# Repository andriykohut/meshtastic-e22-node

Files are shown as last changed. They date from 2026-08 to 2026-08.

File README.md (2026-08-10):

# 433 MHz Meshtastic node

A Meshtastic node built around an ESP32-S3 dev board and an Ebyte E22-400M22S, running on a
2P 18650 pack. Mostly assembled from parts I already had. I wrote this up so I can rebuild it
in a year when I've forgotten how it goes together.

Not a product, not a kit. A dev board, a LoRa module and a GPS on perfboard in a printed box.

## Hardware

| | |
|---|---|
| MCU | ESP32-S3-DevKitC-1 |
| Radio | Ebyte E22-400M22S — SX1268 + PA/LNA, 410–493 MHz |
| GPS | GY-NEO8MV2 (u-blox NEO-8M) |
| Display | SSD1306 128×64, I²C |
| Power | 2× 18650 parallel, TP4056 charger, TPS63020 buck-boost to 3.3 V |
| Region | EU_433 |

## Layout

```
firmware/     variant.h and the platformio env to build it
hardware/     wiring diagrams, netlist, KiCad schematic
docs/         build notes, BOM, troubleshooting
```

## Building the firmware

No stock Meshtastic target fits this hardware, so it needs compiling from source. The E22 has
an external PA whose LNA side needs an RXEN pin driven by the MCU, and nothing prebuilt drives
an arbitrary GPIO for that.

```bash
make upload    # clones meshtastic/firmware into build/firmware, installs variant.h + the
               # platformio env, then flashes
make monitor
```

Then set the region, or it won't transmit at all:

```bash
make configure   # meshtastic --set lora.region EU_433 / lora.modem_preset LONG_FAST
```

See `Makefile` for the full set of targets (`build`, `upload`, `monitor`, `ports`, `configure`,
`validate`, plus `setup`/`harness`/`kicad` for the Python hardware tooling below).

## Wiring

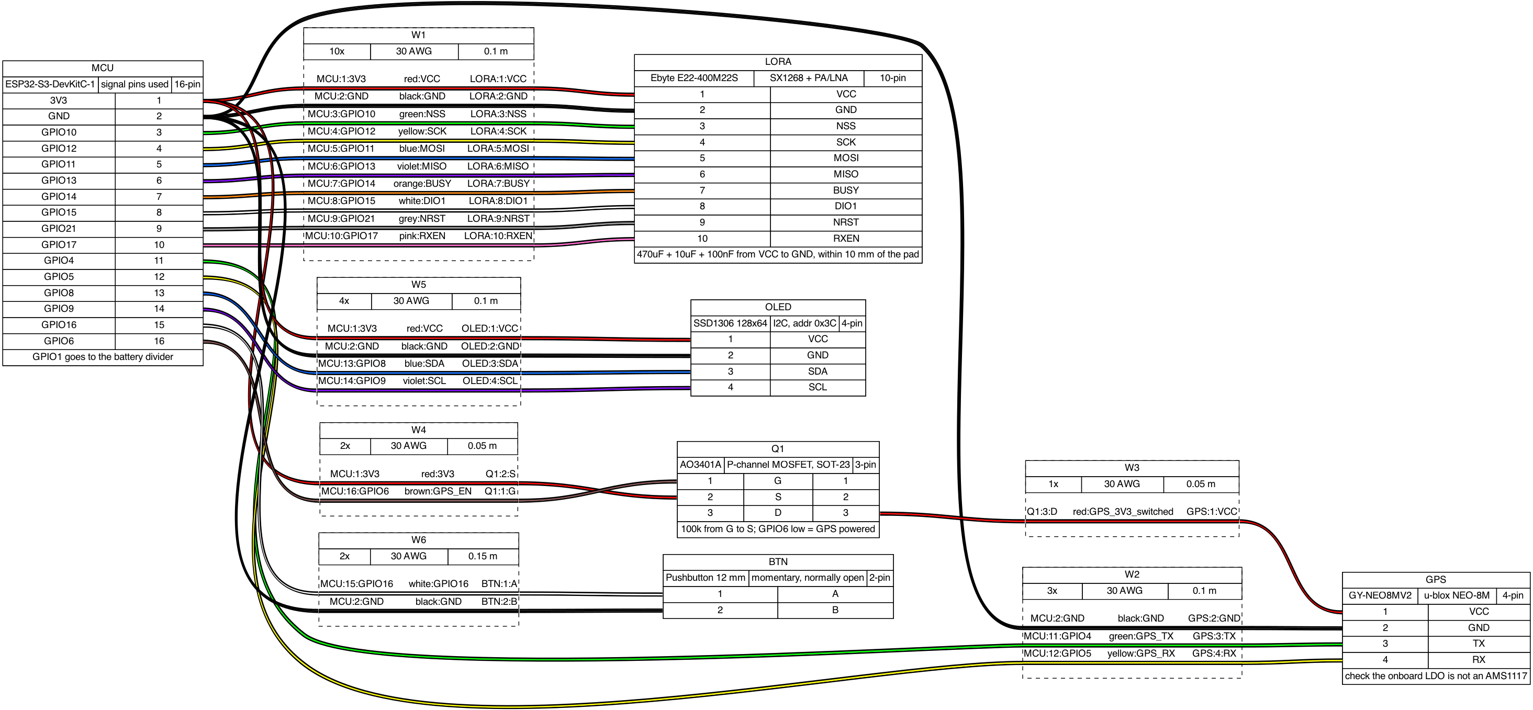
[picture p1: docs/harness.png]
harness


Signal harness above, power section in [docs/power-schematic.svg](docs/power-schematic.svg).
The harness diagram is generated from `hardware/harness.yml` with
[WireViz](https://github.com/wireviz/WireViz) — edit the YAML, run `make harness` (uses
[uv](https://github.com/astral-sh/uv) to manage the Python dependency, see `pyproject.toml`).

Pin labels are signal names, not module pin numbers. Ebyte's numbering varies between
revisions, so check your own datasheet before soldering.

## Things that caught me out

**The E22-400M22S is an SX1268, not an SX1262.** The 900 MHz sibling is the SX1262. Wrong
define, dead radio.

**TXEN is already bonded to DIO2 inside the module.** So `SX126X_DIO2_AS_RF_SWITCH`,
`SX126X_TXEN RADIOLIB_NC`, and leave the TXEN pad alone. Only RXEN needs a GPIO. Driving TXEN
from a pin puts you in contention with DIO2.

**`ADC_CHANNEL` needs the enum, not the IDF macro.** `ADC1_GPIO1_CHANNEL` expands to a plain
`int` in current esp-idf and `Power.cpp` wants an `adc_channel_t`. Use `ADC_CHANNEL_0`.

**A plain buck can't make 3.3 V from one Li-ion cell.** Obvious in hindsight — a step-down
drops out around 3.7 V and you lose most of the discharge curve. Needs a buck-boost.

**The DevKitC is too wide for breadboard-pattern prototyping board.** Its PCB body overhangs
its own pin rows and covers the holes you'd connect to. One accessible row on one side, none on
the other. Plain isolated-pad perfboard sidesteps it, since you wire underneath.

## Status

Works. Runtime is 50–70 h on the 2P pack with the GPS running continuously, which is fine for
what I want but nowhere near what a purpose-built board would do — the DevKitC's USB-UART
bridge and RGB LED are powered permanently and there's no getting around that.

Ideas, in no particular order:

- [ ] Move to a bare ESP32-S3-WROOM-1 for a real low-power version
- [ ] Proper PCB instead of perfboard
- [ ] SHT41 on the spare I²C bus for temperature telemetry
- [ ] Better antenna — the monopole has no counterpoise worth the name

## Licence

MIT, see [LICENSE](LICENSE). The Meshtastic firmware itself is GPL-3.0.

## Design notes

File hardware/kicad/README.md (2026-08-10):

# KiCad schematic

Net-label style — every pin carries a label on its connection point instead of routed wires.
Written for the KiCad 6 file format; 7 and later will open it and offer to upgrade.

Symbols are plain rectangles from an embedded `meshnode` library that isn't installed anywhere,
so KiCad will flag them as not found and fall back to the cached definitions in the file. It
renders and nets fine; rescue or remap them if the warnings are annoying.

Pin numbers are the same strings as pin names, which keeps the netlist readable but isn't what
you want for board layout. Going to a PCB needs real footprints and numeric pin mapping — treat
this as documentation and a netlist source.

`netlist.txt` in the parent directory is the same connectivity as plain text. Export KiCad's
netlist and diff against it if you want to be sure.

Regenerate with `python3 gen_kicad.py` (needs `pip install kiutils`).

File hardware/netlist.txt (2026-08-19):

Meshtastic node - intended netlist
Compare against KiCad's ERC / netlist export to verify the schematic.

+3V3
    U1.3V3
    U2.VCC
    U4.VCC
    Q1.S
    R3.2
    C1.1
    C2.1
    C3.1
    U6.VOUT

GND
    U1.GND
    U2.GND
    U3.GND
    U4.GND
    U5.OUT-
    U6.GND
    C1.2
    C2.2
    C3.2
    C4.2
    R2.2
    SW2.2

VBAT
    U5.OUT+
    SW1.1

VBAT_SW
    SW1.2
    U6.VIN
    R1.1

BATT+
    BT1.+
    BT2.+
    U5.B+

BATT-
    BT1.-
    BT2.-
    U5.B-

USB_5V
    U5.IN+

USB_GND
    U5.IN-

ADC_BATT
    R1.2
    R2.1
    C4.1
    U1.GPIO1

LORA_NSS
    U1.GPIO10
    U2.NSS

LORA_SCK
    U1.GPIO12
    U2.SCK

LORA_MOSI
    U1.GPIO11
    U2.MOSI

LORA_MISO
    U1.GPIO13
    U2.MISO

LORA_BUSY
    U1.GPIO14
    U2.BUSY

LORA_DIO1
    U1.GPIO15
    U2.DIO1

LORA_NRST
    U1.GPIO21
    U2.NRST

LORA_RXEN
    U1.GPIO17
    U2.RXEN

I2C_SDA
    U1.GPIO8
    U4.SDA

I2C_SCL
    U1.GPIO9
    U4.SCL

GPS_TX
    U1.GPIO4
    U3.TX

GPS_RX
    U1.GPIO5
    U3.RX

GPS_EN
    U1.GPIO6
    Q1.G
    R3.1

GPS_3V3_SW
    Q1.D
    U3.VCC

BTN
    U1.GPIO16
    SW2.1

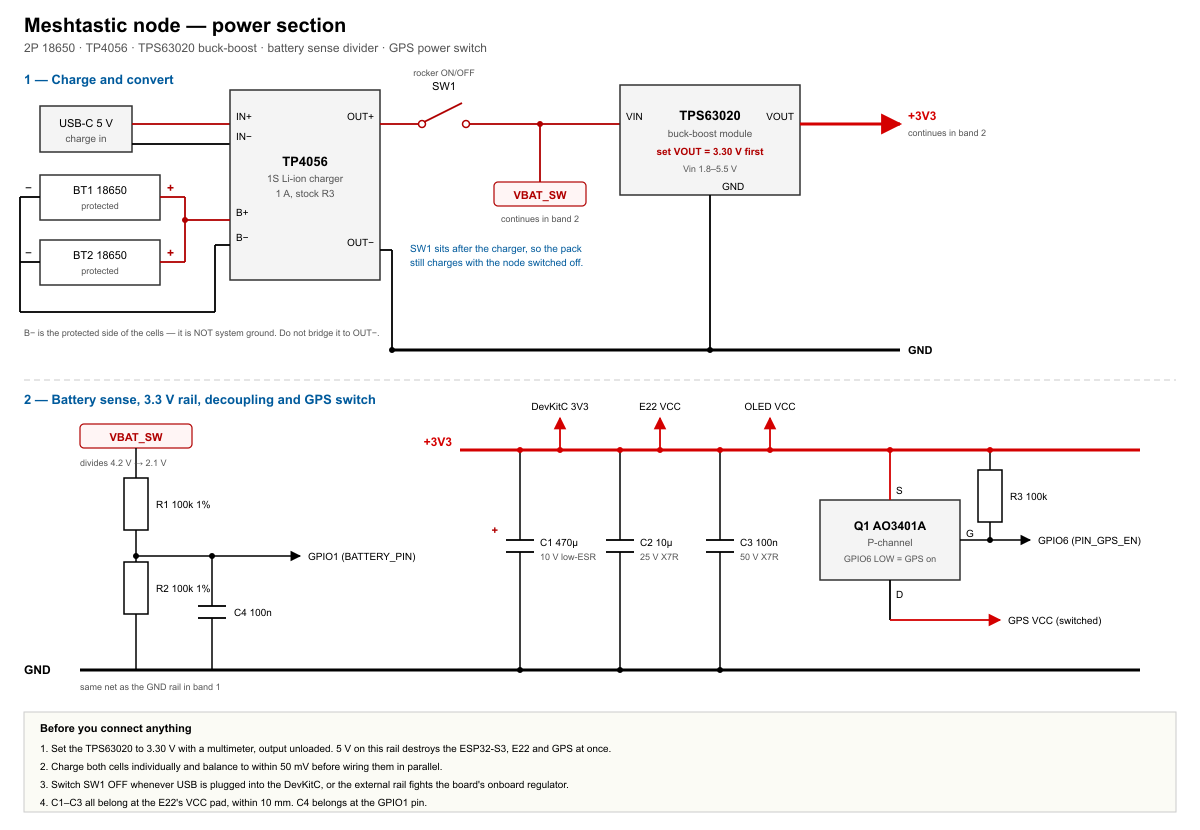
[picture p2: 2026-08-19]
docs/power-schematic.png

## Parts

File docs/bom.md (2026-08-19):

# BOM

Excludes the main modules (ESP32-S3-DevKitC-1, E22-400M22S, GY-NEO8MV2, SSD1306, TP4056),
which I already had, and the antenna and pigtail.

| Qty | Part | Notes |
|---|---|---|
| 2 | 18650, protected, 3400–3500 mAh | Same make and batch. Anything claiming 5000 mAh+ is fake. |
| 2 | 18650 holder, PCB mount | Keystone 1043 style. Two singles wired in parallel — check any "dual" holder isn't series. |
| 1 | TPS63020 buck-boost module | Must be buck-*boost*. Set to 3.30 V before connecting anything. |
| 1 | KCD1-101 rocker switch | Two pins means ON-OFF. Three means changeover, which won't disconnect anything. |
| 1 | 470 µF electrolytic, low-ESR, 105 °C | 330–1000 µF and 6.3–25 V all fine. Low-ESR and 105 °C matter more than the exact numbers. |
| 10 | 10 µF ceramic, 25 V, X7R, 1206 | 16–50 V, 0805–1210. Ceramics lose capacitance under DC bias, so bigger package and higher voltage is better here. Three 10 µF 6.3 V in parallel works if that's all there is. |
| 20 | 100 nF ceramic, 50 V, X7R, 0805 | 16–100 V, 47–220 nF, any package. Not Y5V. |
| 10 | 100 kΩ, 1%, metal film | Any matched pair 47–220 kΩ works; only the ratio matters. R3 is uncritical, 10 kΩ–1 MΩ. |
| 2 | AO3401A P-MOSFET, SOT-23 | Or AO3407, SI2301, DMG2301L, IRLML6402. Needs a gate threshold under ~1.5 V so it turns on at 3.3 V. Optional — skip it and you just lose runtime. |
| 1 | Perfboard, double-sided, plated holes, 80×120 mm | Isolated pads, not stripboard. See build notes. |
| 1 | 2.54 mm female header strip, 40 pin | Cut to length to socket the DevKitC. |
| 1 | 30 AWG silicone wire, assorted | Signals. 22 AWG for power rails. |
| 1 | 12 mm momentary pushbutton, NO | Momentary, not latching — «без фіксації». |
| 1 | M3 brass heat-set inserts | For the printed enclosure. |

Tools that aren't optional: a multimeter (you cannot set the converter or check cell balance
without one), a temperature-controlled iron with a fine tip, and no-clean flux for the E22's
1.27 mm pads.

## Check before ordering

The GPS breakout's regulator. If it's an **AMS1117-3.3** its 1.1 V dropout means 3.3 V in gives
~2.2 V out, below the NEO-8M's 2.7 V minimum, and it will never get a fix. MIC5205 or HT7333
are fine. If it is an AMS1117, bridge its input to output — it has no job on a clean 3.3 V rail.

The TP4056's stock R3 sets a 1 A charge current: ~7-8 h for a full 2P pack (~7000 mAh).

Also worth having: a second, commercial 433 MHz node. One node on its own shows you an empty
node list and nothing else, so you can't tell a broken radio from an empty mesh. Check the band
variant really covers 433 — plenty of "433/470 MHz" boards are matched for 470–510.

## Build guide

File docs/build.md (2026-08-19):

# Build notes

## Power

A single Li-ion cell swings 4.2 V down to 3.0 V, which straddles 3.3 V. That rules out a plain
buck converter, which drops out around 3.6–3.7 V and throws away most of the capacity. The
TPS63020 takes 1.8–5.5 V in and holds 3.3 V across the whole curve.

```
2× 18650 (parallel) → TP4056 → rocker switch → TPS63020 @ 3.3 V → DevKitC 3V3 pin
```

Feeding the `3V3` pin bypasses the DevKitC's own regulator, which can't run from a cell anyway.
The switch is there so the external rail isn't fighting that regulator when USB is plugged in —
switch off before connecting USB. It sits after the charger, so the pack still charges with the
node off.

Set the converter to 3.30 V with a multimeter, output unloaded, before it touches anything else.
These modules arrive at arbitrary trim and 5 V on that rail takes out the ESP32-S3, the E22 and
the GPS in one go.

Plugging in USB while `SW1` is on puts the TPS63020's 3.3 V output directly against the
DevKitC's onboard LDO. Switching off before connecting USB (above) is the actual safeguard;
if you want protection against forgetting that, add a Schottky diode from the TPS63020 output
to the `3V3` pin, or cut the DevKitC's onboard-regulator output trace.

GPIO5 (`GPS_TX_PIN`, the ESP32's UART TX into the GPS's RX) stays driven whenever the firmware
is running, even with GPIO6 cutting GPS VCC. Idle-high TX into an unpowered NEO-8M backfeeds a
few mA through the GPS's input ESD diodes. Only matters in duty-cycled/low-power builds — set
GPIO5 to high-impedance input, or drive it low, whenever GPS power is switched off.

### Decoupling

470 µF + 10 µF + 100 nF from VCC to GND, all within 10 mm of the E22's VCC pad. The electrolytic
handles the PA current bursts, the 100 nF handles the fast edges, and the 10 µF covers the gap
between them where the SX1268's internal switcher lives. A rail that sags under transmit is the
usual reason a radio initialises fine and then has no range.

Solder the 100 nF directly across the module's VCC and GND pads. Long legs add inductance and
defeat the point.

### The 2P pack

Charge both cells individually and get them within ~50 mV of each other before wiring them in
parallel. Connecting a full cell to an empty one puts the difference across nothing but internal
resistance and your wiring. After that they stay balanced on their own.

Series would have meant replacing the TP4056 (single-cell only) and the TPS63020 (5.5 V absolute
max input), and gained nothing, since EU_433 clamps output power far below what the module can do.

## Construction

Isolated-pad perfboard, double-sided, plated through-holes. Not stripboard and not
breadboard-pattern board — the DevKitC's PCB body overhangs its pin rows and covers the holes
you'd otherwise connect through. On perfboard every connection is made on the solder side, so
the overhang doesn't matter.

An 80 × 120 mm board is about 31 × 47 holes; the DevKitC eats under 20% of that.

For the power rails, lay bare tinned 22 AWG wire along a row of pads and solder it at every pad.
Fifteen minutes and you have rails wherever you want them.

To get the header spacing right, mate the female headers onto the DevKitC's pins first, then
lower the whole thing onto the board and solder from underneath while still mated. Alignment
comes out automatic and the headers stay perpendicular, which freehand soldering never does.

E22 and its capacitors at one end, DevKitC socketed in the middle, converter and battery input
at the other. Solder the E22's 1.27 mm pads first while the board is still bare and you can get
an iron in from any angle.

## Antenna

Never key the transmitter without a 50 Ω load on ANT. +22 dBm into an open circuit will kill the
PA and it can happen on the first beacon after boot.

Watch connector gender. RP-SMA male threads happily into an SMA female bulkhead and makes no
centre contact at all, which looks exactly like a working assembly. Look inside: SMA female has a
socket, SMA male has a pin. If the bulkhead has a pin and the antenna has a socket, it's RP-SMA.

## Bring-up

Stage it, or you'll be debugging four things at once.

1. Bare board — flash, check the boot log, check for brownout resets
2. OLED only — Meshtastic splash should appear. I²C scan first if not.
3. GPS — watch for NMEA detection. First cold fix outdoors can take 15 minutes.
4. LoRa, **antenna attached** — look for SX1268 init in the log

## Region

EU_433 caps transmit power well below the module's 22 dBm, because the European 433 MHz
allocation is around 10 mW ERP. The firmware handles the clamping. The E22-400M22S only covers
410–493 MHz so 868 isn't an option with this hardware.

Worth knowing that 433 is heavily congested — RC gear, telemetry, and assorted noise. Expect a
worse noise floor than the link budget suggests.

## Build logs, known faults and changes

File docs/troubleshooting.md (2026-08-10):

# Troubleshooting

## Won't flash

`Failed to connect to ESP32-S3: No serial data received` means esptool never got a reply from
the ROM bootloader.

Force download mode: hold BOOT, press and release RST, release BOOT. The board then waits there
indefinitely. On the native USB port this re-enumerates, so check `pio device list` again before
running.

If that doesn't do it, try the other USB port. On macOS a CP2102N shows up as
`/dev/cu.usbserial-*`, but boards fitted with a CH343 show as `/dev/cu.usbmodem*` — same as the
native USB peripheral — so the port name doesn't tell you which one you're on. Unplug,
`ls /dev/cu.*`, plug one in, list again.

Then pin the port and slow it down:

```ini
upload_port = /dev/cu.usbmodemXXXXXXX
upload_speed = 115200
```

Disconnect everything else while flashing, including the external 3.3 V rail — two supplies
fighting on the `3V3` pin produces exactly this. `-t erase` is optional; skip it on a fresh board.

None of the pins in this variant are ESP32-S3 strapping pins, so a soldering mistake on the LoRa,
GPS, I²C, button or ADC lines can't cause a flashing failure. Look at the cable, the port and
download mode, not your joints.

## Won't compile

`invalid conversion from 'int' to 'adc_channel_t'` in `Power.cpp` — `ADC_CHANNEL` needs an
`adc_channel_t` enum constant, not the IDF's `ADC1_GPIOn_CHANNEL` macro. On ESP32-S3, ADC1 maps
GPIO1–GPIO10 to channels 0–9, so GPIO1 is `ADC_CHANNEL_0`.

Variant macros drift between Meshtastic releases and one the firmware never reads produces no
error at all — it just silently does nothing. Worth checking the less universal ones:

```bash
grep -rn "TCXO_OPTIONAL\|GPS_EN_ACTIVE\|PIN_GPS_EN\|SX126X_RXEN" src/ | head
```

## Radio

| Symptom | Cause |
|---|---|
| Radio init failed | `USE_SX1262` instead of `USE_SX1268`; BUSY/NRST/DIO1 miswired; SPI run too long; TCXO define missing |
| Inits, transmits, never receives | RXEN not wired, or on the wrong GPIO |
| Reboots when transmitting | Not enough bulk capacitance at the E22, or the converter is undersized |
| Frequency offset, patchy links | TCXO voltage — try 1.8, then 3.3, then remove the define |
| BUSY stuck high, locks up after working | Known with this module under RadioLib. More bulk capacitance, shorter SPI, `TCXO_OPTIONAL`. See meshtastic/firmware#6692 |

## GPS

No fix ever: TX/RX swapped, no view of the sky, or the breakout's AMS1117 regulator dropping the
rail below 2.7 V. Check which LDO is fitted.

GPS never powers down: `PIN_GPS_EN` or `GPS_EN_ACTIVE` not supported in your firmware version, so
the P-FET gate is left to the pull-up. Grep for them.

## Other

Blank screen — wrong I²C pins, missing pull-ups, or a display at 0x3D rather than 0x3C.

Nonsense battery percentage — `ADC_MULTIPLIER` wrong, divider tapped before the switch, or the
100 nF on the ADC node missing. With 5% resistors, measure the pair and set `ADC_MULTIPLIER` to
the ratio you actually built.

Long press doesn't power off — it can't. There's no PMU or latch circuit here, so "shutdown" is
deep sleep and the dev board's USB-UART bridge keeps drawing. The rocker switch is the real off.

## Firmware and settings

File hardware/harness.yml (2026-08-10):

metadata:
  title: Meshtastic node - signal harness
  description: ESP32-S3-DevKitC-1 + E22-400M22S (SX1268) + GY-NEO8MV2 + SSD1306
  notes: >
    Labels are signal names, not module pin numbers. TXEN, DIO2 and DIO3 on the E22
    are unconnected by design.

options:
  fontname: DejaVu Sans
  bgcolor: WH
  color_mode: full

connectors:
  MCU:
    type: ESP32-S3-DevKitC-1
    subtype: signal pins used
    pinlabels:
      - 3V3
      - GND
      - GPIO10
      - GPIO12
      - GPIO11
      - GPIO13
      - GPIO14
      - GPIO15
      - GPIO21
      - GPIO17
      - GPIO4
      - GPIO5
      - GPIO8
      - GPIO9
      - GPIO16
      - GPIO6
    notes: GPIO1 goes to the battery divider

  LORA:
    type: Ebyte E22-400M22S
    subtype: SX1268 + PA/LNA
    pinlabels: [VCC, GND, NSS, SCK, MOSI, MISO, BUSY, DIO1, NRST, RXEN]
    notes: 470uF + 10uF + 100nF from VCC to GND, within 10 mm of the pad

  GPS:
    type: GY-NEO8MV2
    subtype: u-blox NEO-8M
    pinlabels: [VCC, GND, TX, RX]
    notes: check the onboard LDO is not an AMS1117

  OLED:
    type: SSD1306 128x64
    subtype: I2C, addr 0x3C
    pinlabels: [VCC, GND, SDA, SCL]

  BTN:
    type: Pushbutton 12 mm
    subtype: momentary, normally open
    pinlabels: [A, B]

  Q1:
    type: AO3401A
    subtype: P-channel MOSFET, SOT-23
    pinlabels: [G, S, D]
    notes: 100k from G to S; GPIO6 low = GPS powered

cables:
  W1:
    category: bundle
    gauge: 30 AWG
    length: 0.1
    colors: [RD, BK, GN, YE, BU, VT, OG, WH, GY, PK]
    wirelabels: [VCC, GND, NSS, SCK, MOSI, MISO, BUSY, DIO1, NRST, RXEN]

  W2:
    category: bundle
    gauge: 30 AWG
    length: 0.1
    colors: [BK, GN, YE]
    wirelabels: [GND, GPS_TX, GPS_RX]

  W3:
    category: bundle
    gauge: 30 AWG
    length: 0.05
    colors: [RD]
    wirelabels: [GPS_3V3_switched]

  W4:
    category: bundle
    gauge: 30 AWG
    length: 0.05
    colors: [RD, BN]
    wirelabels: [3V3, GPS_EN]

  W5:
    category: bundle
    gauge: 30 AWG
    length: 0.1
    colors: [RD, BK, BU, VT]
    wirelabels: [VCC, GND, SDA, SCL]

  W6:
    category: bundle
    gauge: 30 AWG
    length: 0.15
    colors: [WH, BK]
    wirelabels: [GPIO16, GND]

connections:
  -
    - MCU: [1, 2, 3, 4, 5, 6, 7, 8, 9, 10]
    - W1: [1, 2, 3, 4, 5, 6, 7, 8, 9, 10]
    - LORA: [1, 2, 3, 4, 5, 6, 7, 8, 9, 10]

  -
    - MCU: [2, 11, 12]
    - W2: [1, 2, 3]
    - GPS: [2, 3, 4]

  -
    - Q1: [3]
    - W3: [1]
    - GPS: [1]

  -
    - MCU: [1, 16]
    - W4: [1, 2]
    - Q1: [2, 1]

  -
    - MCU: [1, 2, 13, 14]
    - W5: [1, 2, 3, 4]
    - OLED: [1, 2, 3, 4]

  -
    - MCU: [15, 2]
    - W6: [1, 2]
    - BTN: [1, 2]

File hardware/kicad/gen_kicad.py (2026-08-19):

#!/usr/bin/env python3
"""
Generates meshtastic-node.kicad_sch.

Every pin gets a local label sitting on its connection point, so connectivity
comes from labels rather than routed wires and placement only affects readability.
If the labels come out mirrored top-to-bottom, flip `sy - py` to `sy + py` in the
label loop near the bottom.
"""
import uuid as U
from pathlib import Path
from kiutils.schematic import Schematic
from kiutils.symbol import Symbol, SymbolPin
from kiutils.items.common import Position, Stroke, Property, Effects, Font, Justify
from kiutils.items.syitems import SyRect, Fill
from kiutils.items.schitems import SchematicSymbol, LocalLabel, SymbolInstance

PITCH = 2.54
NICK = "meshnode"

HERE = Path(__file__).resolve().parent
SCH_PATH = HERE / "meshtastic-node.kicad_sch"
NETLIST_PATH = HERE.parent / "netlist.txt"


def make_symbol(name, left_pins, right_pins, ref_prefix, value, half_w=12.7):
    """Rectangle symbol; pins evenly spaced down each side."""
    rows = max(len(left_pins), len(right_pins), 1)
    half_h = max((rows - 1) * PITCH / 2 + PITCH, PITCH * 2)

    sym = Symbol.create_new(id=f"{NICK}:{name}", reference=ref_prefix, value=value)
    sym.properties[0].position = Position(0, half_h + 2.54, 0)
    sym.properties[1].position = Position(0, -half_h - 2.54, 0)

    g = Symbol(entryName=name, unitId=0, styleId=1)
    g.graphicItems.append(SyRect(
        start=Position(-half_w, half_h), end=Position(half_w, -half_h),
        stroke=Stroke(width=0.254, type='default'), fill=Fill(type='background')))

    p = Symbol(entryName=name, unitId=1, styleId=1)
    geometry = {}

    def add(pins, side):
        n = len(pins)
        if not n:
            return
        top = (n - 1) * PITCH / 2
        for i, pin_name in enumerate(pins):
            y = top - i * PITCH
            if side == 'L':
                pos, rot = Position(-half_w - PITCH, y, 0), 0
            else:
                pos, rot = Position(half_w + PITCH, y, 180), 180
            p.pins.append(SymbolPin(
                electricalType='passive', graphicalStyle='line',
                position=Position(pos.X, pos.Y, rot), length=PITCH,
                name=pin_name, number=pin_name))
            geometry[pin_name] = (pos.X, pos.Y)

    add(left_pins, 'L')
    add(right_pins, 'R')
    sym.units += [g, p]
    return sym, geometry


# ---------------------------------------------------------------- definitions
DEFS = {
    "ESP32-S3-DevKitC-1": (
        ["3V3", "GND"],
        ["GPIO1", "GPIO4", "GPIO5", "GPIO6", "GPIO8", "GPIO9", "GPIO10", "GPIO11",
         "GPIO12", "GPIO13", "GPIO14", "GPIO15", "GPIO16", "GPIO17", "GPIO21"],
        "U", "ESP32-S3-DevKitC-1", 17.78),
    "E22-400M22S": (
        ["VCC", "GND"],
        ["NSS", "SCK", "MOSI", "MISO", "BUSY", "DIO1", "NRST", "RXEN"],
        "U", "E22-400M22S (SX1268)", 17.78),
    "GY-NEO8MV2": (["VCC", "GND"], ["TX", "RX"], "U", "GY-NEO8MV2", 12.7),
    "SSD1306": (["VCC", "GND"], ["SDA", "SCL"], "U", "SSD1306 128x64", 12.7),
    "TP4056": (["IN+", "IN-", "B+", "B-"], ["OUT+", "OUT-"], "U", "TP4056", 12.7),
    "TPS63020": (["VIN", "GND"], ["VOUT"], "U", "TPS63020 buck-boost", 15.24),
    "AO3401A": (["G"], ["S", "D"], "Q", "AO3401A", 10.16),
    "R": (["1"], ["2"], "R", "100k", 5.08),
    "C": (["1"], ["2"], "C", "100n", 5.08),
    "CP": (["1"], ["2"], "C", "470u", 5.08),
    "SW": (["1"], ["2"], "SW", "switch", 6.35),
    "BATT": (["+"], ["-"], "BT", "18650", 6.35),
}

symbols, geoms = {}, {}
for name, (lp, rp, pref, val, hw) in DEFS.items():
    s, g = make_symbol(name, lp, rp, pref, val, hw)
    symbols[name], geoms[name] = s, g

# ------------------------------------------------------------------ placement
# (ref, symbol, x, y, value)
PLACED = [
    ("U1", "ESP32-S3-DevKitC-1", 90, 120, "ESP32-S3-DevKitC-1"),
    ("U2", "E22-400M22S", 200, 105, "E22-400M22S (SX1268)"),
    ("U3", "GY-NEO8MV2", 200, 185, "GY-NEO8MV2"),
    ("U4", "SSD1306", 200, 225, "SSD1306 128x64"),
    ("U5", "TP4056", 90, 220, "TP4056"),
    ("U6", "TPS63020", 150, 265, "TPS63020"),
    ("Q1", "AO3401A", 265, 185, "AO3401A"),
    ("R1", "R", 310, 100, "100k 1%"),
    ("R2", "R", 310, 125, "100k 1%"),
    ("R3", "R", 310, 150, "100k"),
    ("C1", "CP", 350, 100, "470u 10V low-ESR"),
    ("C2", "C", 350, 125, "10u 25V X7R"),
    ("C3", "C", 350, 150, "100n 50V X7R"),
    ("C4", "C", 350, 175, "100n 50V X7R"),
    ("SW1", "SW", 90, 265, "rocker ON/OFF"),
    ("SW2", "SW", 265, 240, "user button"),
    ("BT1", "BATT", 40, 205, "18650 protected"),
    ("BT2", "BATT", 40, 235, "18650 protected"),
]

# --------------------------------------------------------------------- nets
NETS = {
    "+3V3":      [("U1", "3V3"), ("U2", "VCC"), ("U4", "VCC"), ("Q1", "S"),
                  ("R3", "2"), ("C1", "1"), ("C2", "1"), ("C3", "1"), ("U6", "VOUT")],
    "GND":       [("U1", "GND"), ("U2", "GND"), ("U3", "GND"), ("U4", "GND"),
                  ("U5", "OUT-"), ("U6", "GND"), ("C1", "2"),
                  ("C2", "2"), ("C3", "2"), ("C4", "2"), ("R2", "2"), ("SW2", "2")],
    "VBAT":      [("U5", "OUT+"), ("SW1", "1")],
    "VBAT_SW":   [("SW1", "2"), ("U6", "VIN"), ("R1", "1")],
    "BATT+":     [("BT1", "+"), ("BT2", "+"), ("U5", "B+")],
    "BATT-":     [("BT1", "-"), ("BT2", "-"), ("U5", "B-")],
    "USB_5V":    [("U5", "IN+")],
    "USB_GND":   [("U5", "IN-")],
    "ADC_BATT":  [("R1", "2"), ("R2", "1"), ("C4", "1"), ("U1", "GPIO1")],
    "LORA_NSS":  [("U1", "GPIO10"), ("U2", "NSS")],
    "LORA_SCK":  [("U1", "GPIO12"), ("U2", "SCK")],
    "LORA_MOSI": [("U1", "GPIO11"), ("U2", "MOSI")],
    "LORA_MISO": [("U1", "GPIO13"), ("U2", "MISO")],
    "LORA_BUSY": [("U1", "GPIO14"), ("U2", "BUSY")],
    "LORA_DIO1": [("U1", "GPIO15"), ("U2", "DIO1")],
    "LORA_NRST": [("U1", "GPIO21"), ("U2", "NRST")],
    "LORA_RXEN": [("U1", "GPIO17"), ("U2", "RXEN")],
    "I2C_SDA":   [("U1", "GPIO8"), ("U4", "SDA")],
    "I2C_SCL":   [("U1", "GPIO9"), ("U4", "SCL")],
    "GPS_TX":    [("U1", "GPIO4"), ("U3", "TX")],
    "GPS_RX":    [("U1", "GPIO5"), ("U3", "RX")],
    "GPS_EN":    [("U1", "GPIO6"), ("Q1", "G"), ("R3", "1")],
    "GPS_3V3_SW":[("Q1", "D"), ("U3", "VCC")],
    "BTN":       [("U1", "GPIO16"), ("SW2", "1")],
}

# ------------------------------------------------------------------- assemble
sch = Schematic.create_new()
from kiutils.items.common import PageSettings
sch.paper = PageSettings(paperSize="A2")
from kiutils.items.common import TitleBlock
sch.titleBlock = TitleBlock()
sch.titleBlock.title = "Meshtastic node - ESP32-S3 + E22-400M22S"
sch.titleBlock.comment = {1: "Net-label schematic; labels sit on pin connection points"}
for s in symbols.values():
    sch.libSymbols.append(s)

placement = {r: (n, x, y) for r, n, x, y, v in PLACED}
uuids = {}
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

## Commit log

2026-08-10 Add Makefile with uv-based Python setup and firmware build targets
    Wraps hardware tooling (wireviz, kiutils via uv/pyproject.toml) and the
    Meshtastic firmware clone/build/upload/monitor/configure/validate steps
    in make targets so they don't need to be copy-pasted from the docs.
2026-08-17 Move LORA_DIO1 to GPIO17 and leave RXEN unconnected
    The E22-400M22S's DIO1 is soldered to GPIO17, not GPIO15, and DIO2_AS_RF_SWITCH
    covers RX/TX switching without a dedicated RXEN GPIO. Updates the harness,
    netlist, and KiCad schematic to match.
    [meshtastic-node.kicad_sch]
2026-08-18 Revert "Move LORA_DIO1 to GPIO17 and leave RXEN unconnected"
    This reverts commit b10729740e6e90aba9a7bb52932b40f3d5bce145.
    [meshtastic-node.kicad_sch]
2026-08-19 Fix TP4056 ground short, build idempotency, and doc issues from code review
    - Split U5.IN- onto a dedicated USB_GND net instead of GND, so the
    netlist/KiCad schematic no longer bridges the TP4056's low-side
    protection MOSFETs (netlist.txt, gen_kicad.py, kicad_sch)
    - gen_kicad.py: deterministic uuid5 symbol/pin UUIDs and pathlib-anchored
    output paths, so re-running produces no diff and always writes
    hardware/netlist.txt regardless of cwd
    - Makefile: firmware-install now copies platformio-env.ini into
    variants/<env>/platformio.ini (picked up via PlatformIO's extra_configs)
    instead of a grep-guarded append, so edits always take effect; harness
    target now outputs directly to docs/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
    [meshtastic-node.kicad_sch]
